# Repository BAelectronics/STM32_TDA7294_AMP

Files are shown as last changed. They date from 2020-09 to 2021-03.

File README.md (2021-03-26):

# Kapcsolódó videók / Related videos
[Part 1 (showing)](https://youtu.be/A-13wsFyjP8)
The language of the video is Hungarian, but English subtitles are available.

[Part 2 (HW & SW részletek)](https://youtu.be/WkM5X-X5rjU)

# STM32 vezérelt TDA7294 erősítő
A videóban bemutatott és a projekthez tartozó fájlok, rajzok, kódok stb.

A vezérlőpanel kapcsolása és nyákterve KiCad 5.1 programmal készült.
Az erősítőpanel és a táppanel Sprint Layout 5.0 programmal készült.
Az erősítőpanel kapcsolási rajza nem saját tervezés, ez képként megtalálható.

# STM32 Controlled TDA7294 Amplifier
Files, schematics, codes, etc. Everything what presented in the video and associated with the project.

The control board schematic and PCB designed with KiCad 5.1.
The amplifier board and power supply board designed with Sprint Layout 5.0.
The schematic of the amplifier board is not my own design, it can be found as picture.

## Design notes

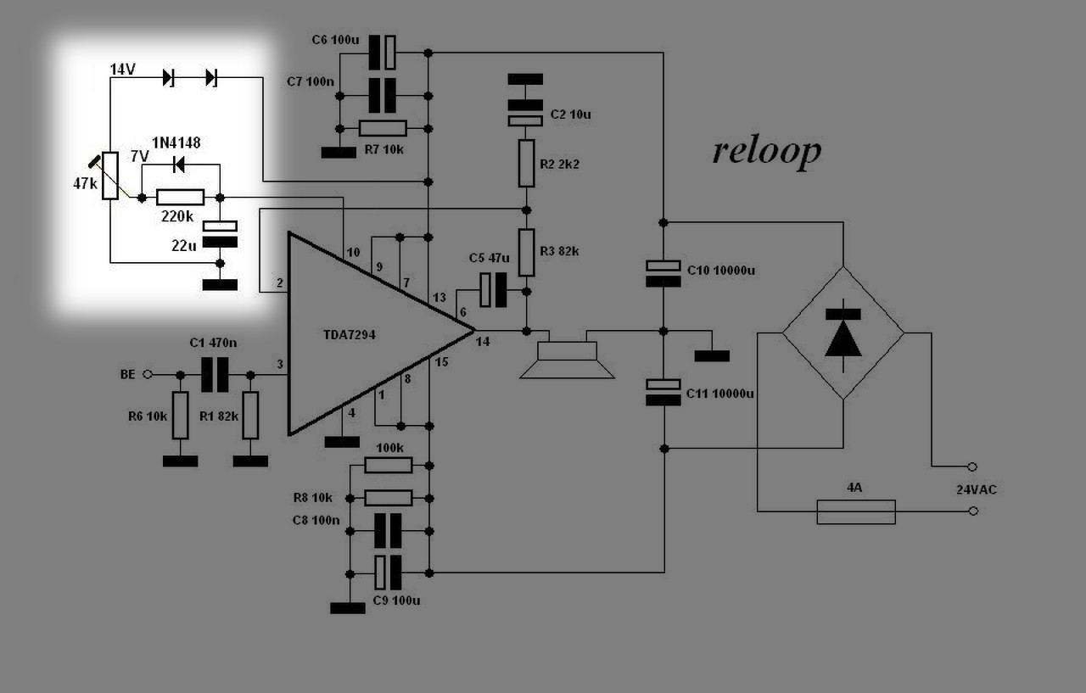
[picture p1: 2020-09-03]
1.4 ENG/Amplifier + power supply/Amplifier additional schematic.JPG

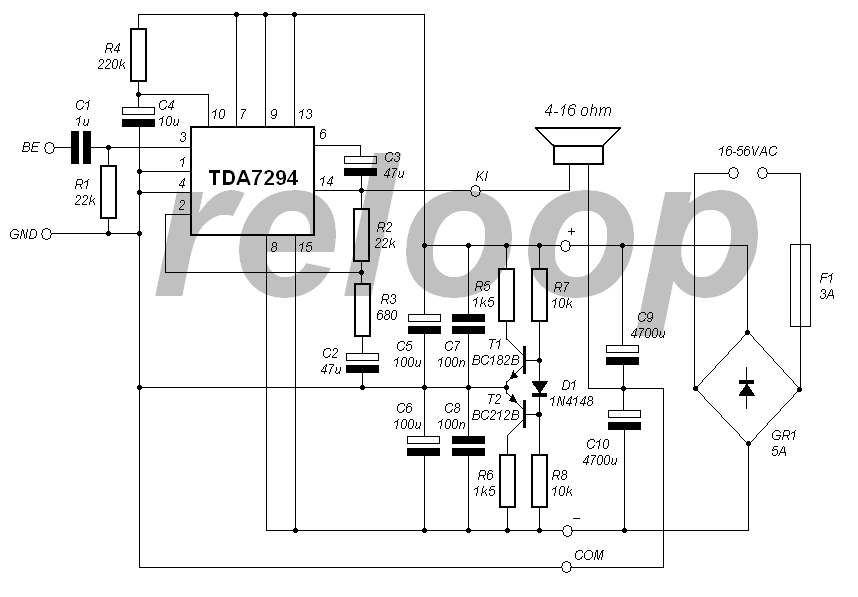
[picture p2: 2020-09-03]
1.4 ENG/Amplifier + power supply/Amplifier base schematic.PNG

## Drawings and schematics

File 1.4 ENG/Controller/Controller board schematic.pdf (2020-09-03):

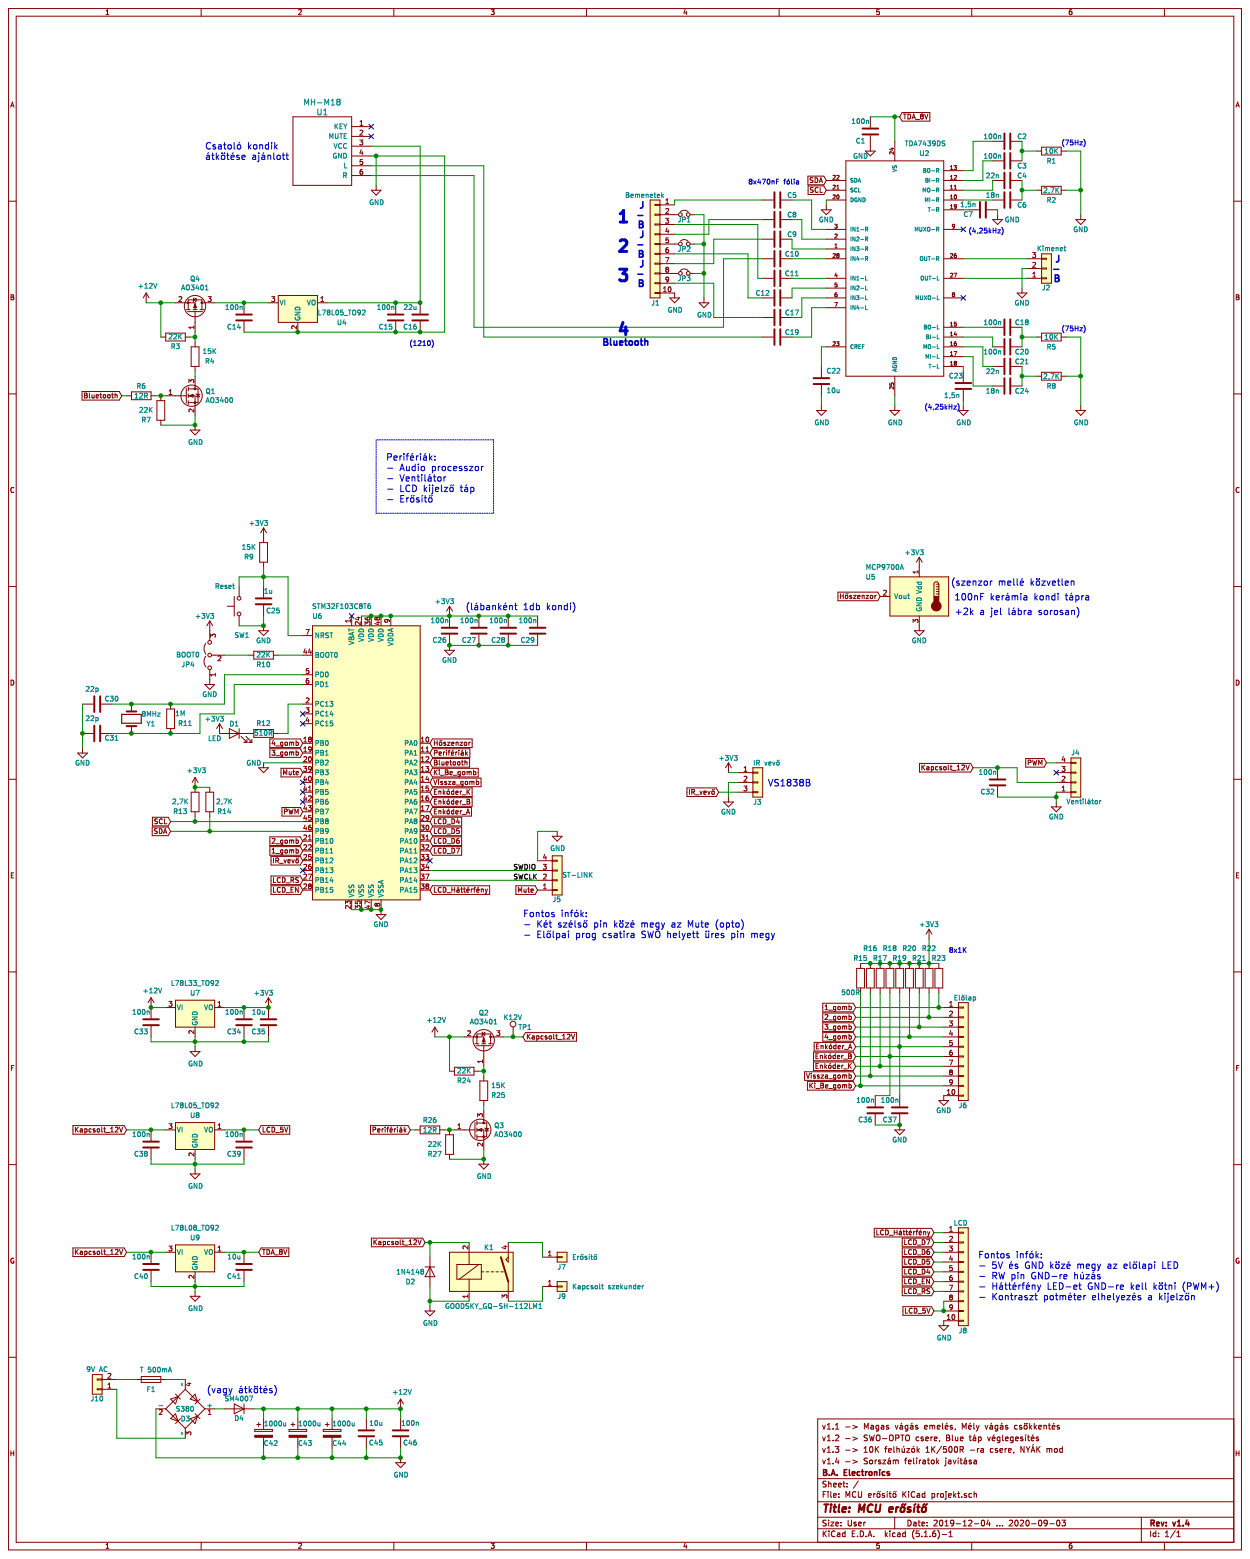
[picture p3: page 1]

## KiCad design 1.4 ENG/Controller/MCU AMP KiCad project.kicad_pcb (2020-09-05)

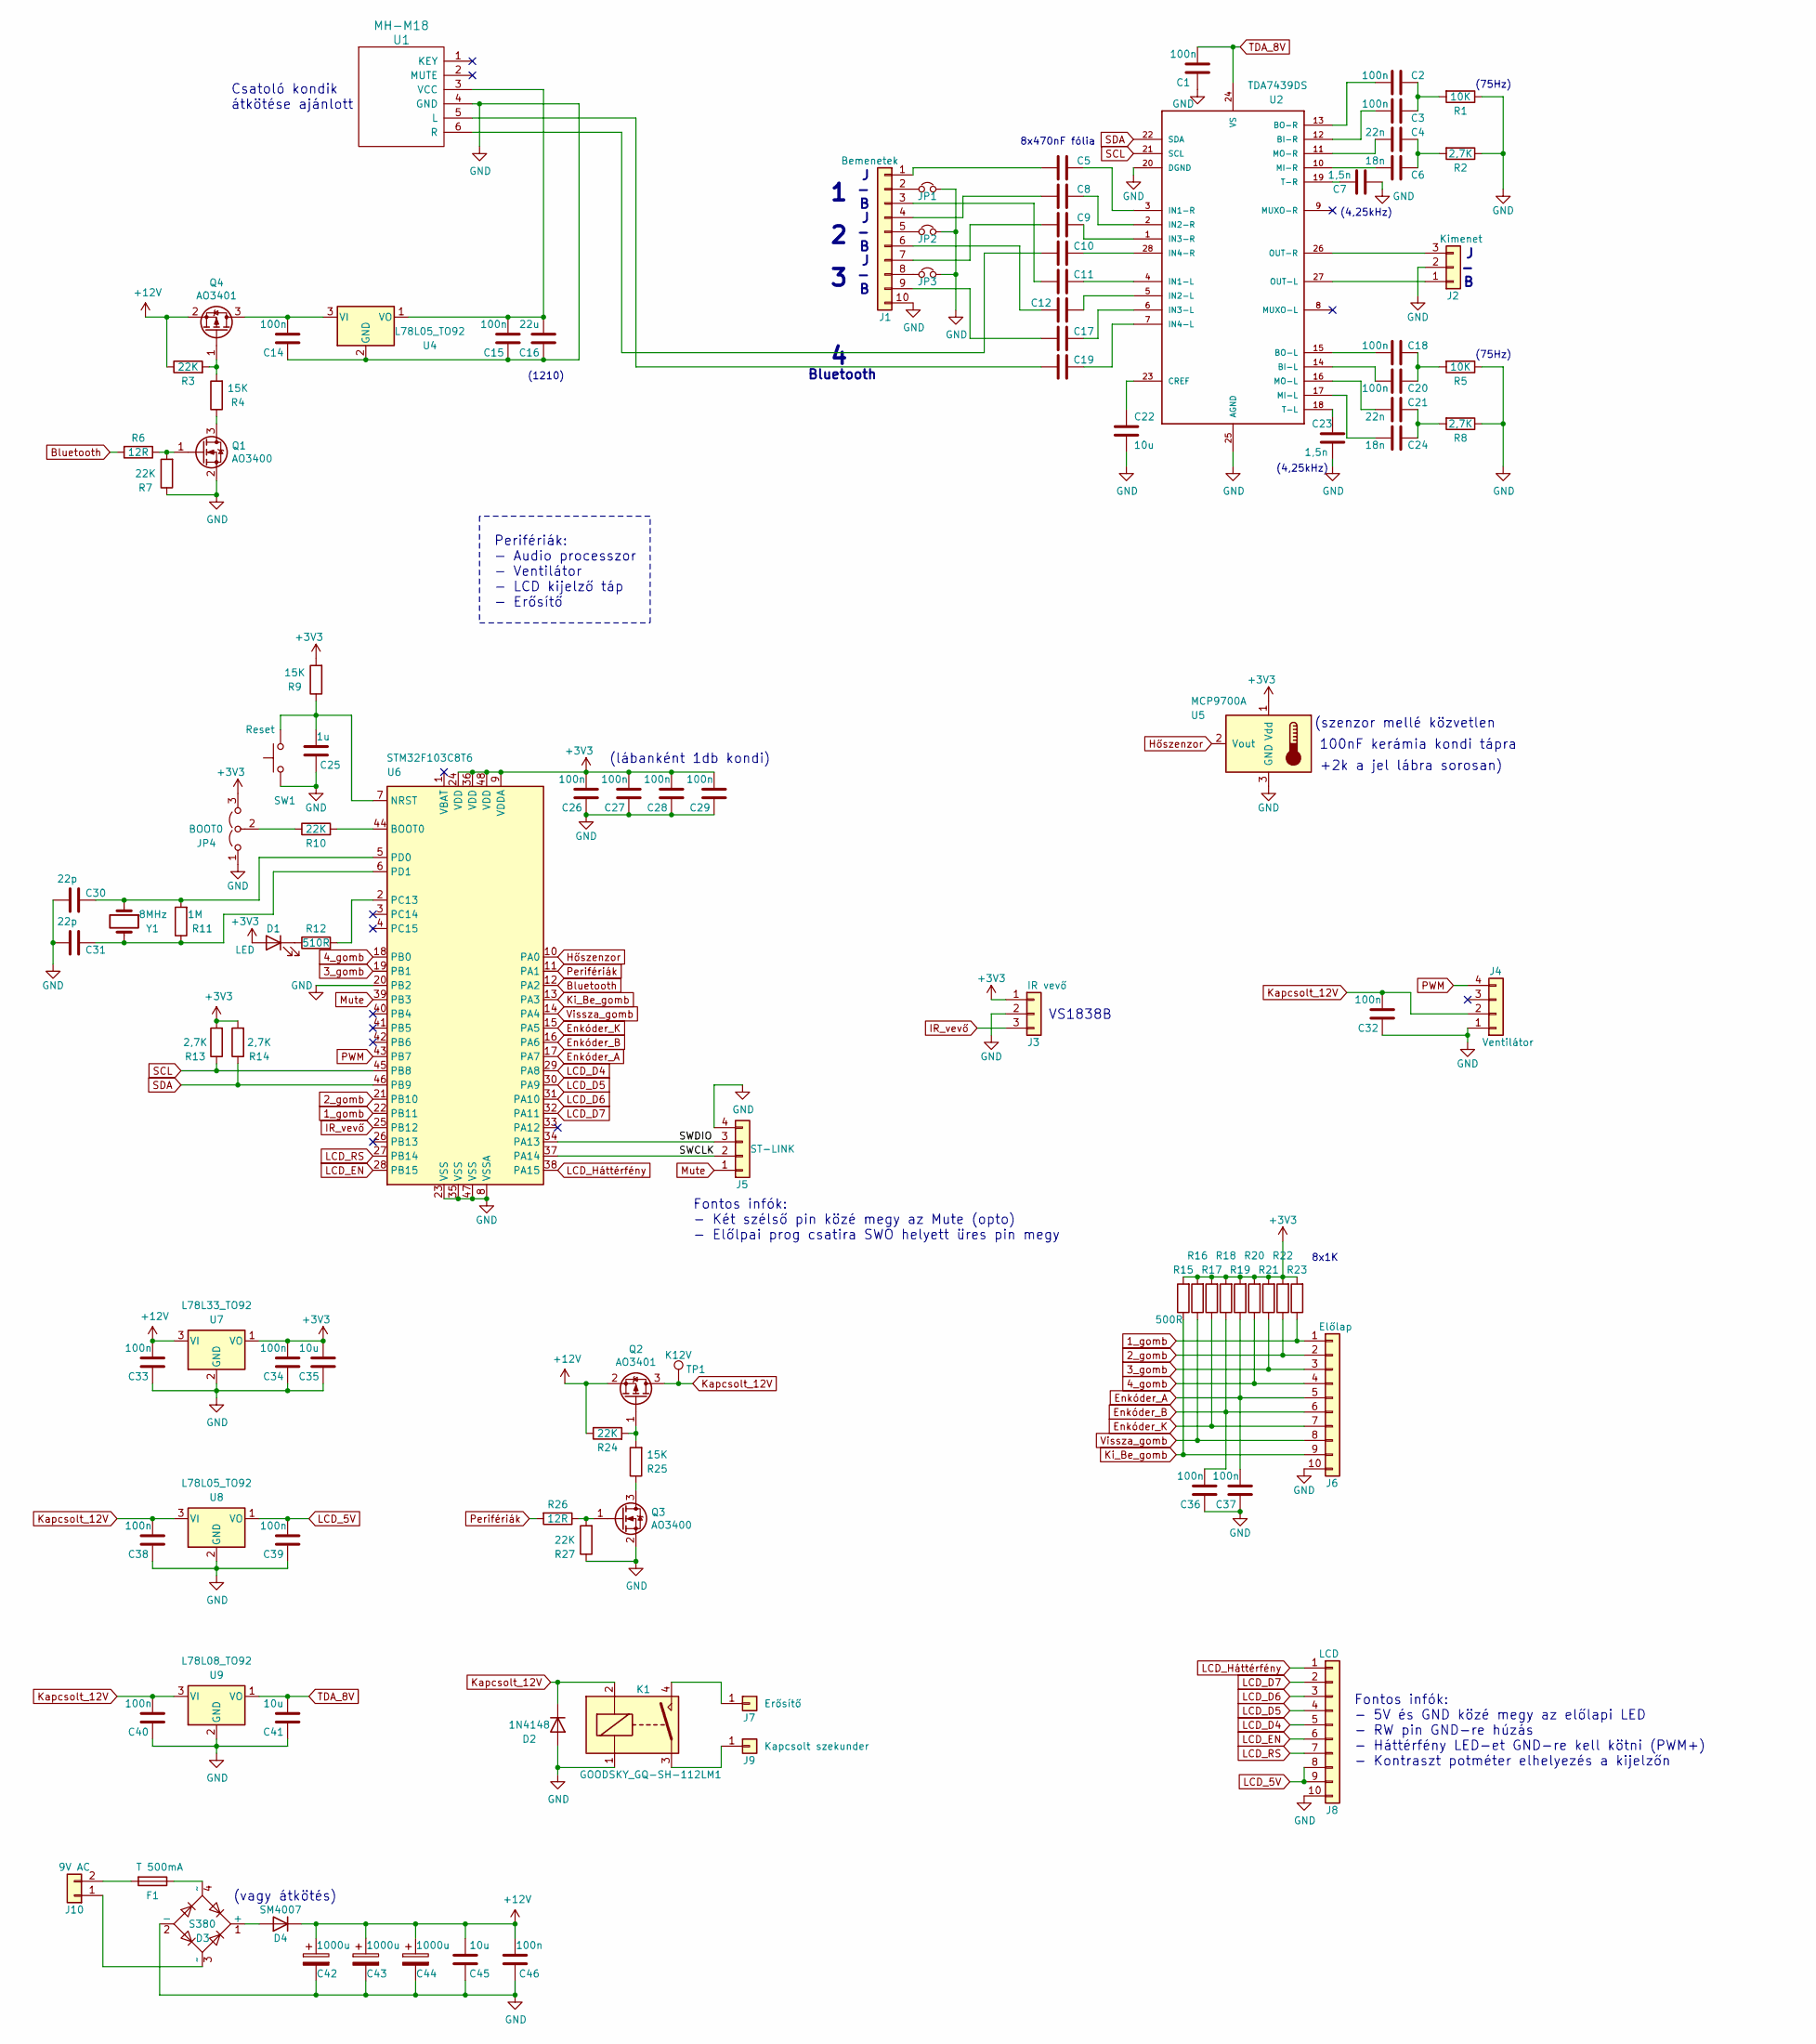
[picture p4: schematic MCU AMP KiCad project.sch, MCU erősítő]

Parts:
C1, C14, C15, C26, C27, C28, C29, C32, C33, C34, C36, C37, C38, C39, C40, C46: 100n; C_0805_2012Metric
C2, C3, C18, C20: 100n; C_Rect_L7.0mm_W2.5mm_P5.00mm
C4, C21: 22n; C_Rect_L7.0mm_W2.5mm_P5.00mm
C5, C8, C9, C10, C11, C12, C17, C19: 470n; C_Rect_L7.2mm_W3.5mm_P5.00mm_FKS2_FKP2_MKS2_MKP2
C6, C24: 18n; C_Rect_L7.0mm_W2.5mm_P5.00mm
C7, C23: 1,5n; C_Rect_L7.0mm_W2.5mm_P5.00mm
C16: 22u; C_1210_3225Metric
C22, C35, C41, C45: 10u; C_1206_3216Metric
C25: 1u; C_0805_2012Metric
C30, C31: 22p; C_0805_2012Metric
C42, C43, C44: 1000u; CP_Radial_D8.0mm_P3.50mm
D1: LED; LED_0805_2012Metric
D2: 1N4148; D_DO-35_SOD27_P7.62mm_Horizontal
D3: S380; Diode_Bridge_TO-269AA
D4: SM4007; D_MELF
F1: T 500mA; Fuse_Littelfuse_372_D8.50mm
J1: Bemenetek; JST_PH_B10B-PH-K_1x10_P2.00mm_Vertical
J2: Kimenet; JST_PH_B3B-PH-K_1x03_P2.00mm_Vertical
J3: IR vevő; JST_PH_B3B-PH-K_1x03_P2.00mm_Vertical
J4: Ventilátor; Molex_KK-254_AE-6410-04A_1x04_P2.54mm_Vertical
J5: ST-LINK; JST_PH_B4B-PH-K_1x04_P2.00mm_Vertical
J6: Előlap; JST_PH_B10B-PH-K_1x10_P2.00mm_Vertical
J7: Erősítő; SolderWirePad_1x02_P5.08mm_Drill1.5mm_saru
J8: LCD; JST_PH_B10B-PH-K_1x10_P2.00mm_Vertical
J9: Kapcsolt szekunder; SolderWirePad_1x02_P5.08mm_Drill1.5mm_saru
J10: 9V AC; TerminalBlock_RND_205-00012_1x02_P5.00mm_Horizontal
JP1: Jumper_1_GND; SolderJumper-2_P1.3mm_Open_Pad1.0x1.5mm
JP2: Jumper_2_GND; SolderJumper-2_P1.3mm_Open_Pad1.0x1.5mm
JP3: Jumper_3_GND; SolderJumper-2_P1.3mm_Open_Pad1.0x1.5mm
JP4: BOOT0; PinHeader_1x03_P2.54mm_Vertical
K1: GOODSKY_GQ-SH-112LM1
Q1, Q3: AO3400; SOT-23
Q2, Q4: AO3401; SOT-23
R1, R5: 10K; R_0805_2012Metric
R2, R8, R13, R14: 2,7K; R_0805_2012Metric
R3, R7, R10, R24, R27: 22K; R_0805_2012Metric
R4, R9: 15K; R_0805_2012Metric
R6, R26: 12R; R_0805_2012Metric
R11: 1M; R_0805_2012Metric
R12: 510R; R_0805_2012Metric
R15: 500R; R_0805_2012Metric
R16, R17, R18, R19, R20, R21, R22, R23: 1K; R_0805_2012Metric
R25: 15K; R_1206_3216Metric
SW1: Reset; SW_SPST_FSMSM
TP1: K12V; TestPoint_Pad_D1.0mm
U1: MH-M18; MH-M18_Bluetooth_Audio
U2: TDA7439DS; SOIC-28W_7.5x17.9mm_P1.27mm
U4, U8: L78L05_TO92; TO-92_Inline_mod
U5: MCP9700A; JST_PH_B3B-PH-K_1x03_P2.00mm_Vertical
U6: STM32F103C8T6; LQFP-48_7x7mm_P0.5mm
U7: L78L33_TO92; TO-92_Inline_mod
U9: L78L08_TO92; TO-92_Inline_mod
Y1: 8MHz; Crystal_HC49-U_Vertical

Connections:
1_gomb: J6.1, R23.1, U6.22 (PB11)
2_gomb: J6.2, R22.1, U6.21 (PB10)
3_gomb: J6.3, R21.1, U6.19 (PB1)
4_gomb: J6.4, R20.1, U6.18 (PB0)
+3V3: C26.2, C27.2, C28.2, C29.2, C34.2, C35.2, D1.2 (A), J3.1, JP4.3 (B), R9.2, R13.2, R14.2, R15.2, R16.2, R17.2, R18.2, R19.2, R20.2, R21.2, R22.2, R23.2, U5.1 (Vdd), U6.9 (VDDA), U6.24 (VDD), U6.36 (VDD), U6.48 (VDD), U7.1 (VO)
+12V: C33.2, C42.1, C43.1, C44.1, C45.2, C46.2, D4.1 (K), Q2.2 (S), Q4.2 (S), R3.1, R24.1, U7.3 (VI)
/SWCLK: J5.2, U6.37 (PA14)
/SWDIO: J5.3, U6.34 (PA13)
Bluetooth: R6.2, U6.12 (PA2)
Enkóder_A: C37.2, J6.5, R19.1, U6.17 (PA7)
Enkóder_B: C36.2, J6.6, R18.1, U6.16 (PA6)
Enkóder_K: J6.7, R17.1, U6.15 (PA5)
GND: C1.1, C7.2, C14.1, C15.1, C16.1, C22.1, C23.1, C25.1, C26.1, C27.1, C28.1, C29.1, C30.1, C31.1, C32.1, C33.1, C34.1, C35.1, C36.1, C37.1, C38.1, C39.1, C40.1, C41.1, C42.2, C43.2, C44.2, C45.1, C46.1, D2.2 (A), D3.2 (-), J1.10, J2.2, J3.2, J4.1, J5.4, J6.10, J8.10, JP1.2, JP2.2, JP3.2, JP4.1 (A), K1.1, Q1.2 (S), Q3.2 (S), R1.1, R2.1, R5.1, R7.1, R8.1, R27.1, SW1.1, U1.4 (GND), U2.20 (DGND), U2.25 (AGND), U4.2 (GND), U5.3 (GND), U6.8 (VSSA), U6.20 (PB2), U6.23 (VSS), U6.35 (VSS), U6.47 (VSS), U7.2 (GND), U8.2 (GND), U9.2 (GND)
Hőszenzor: U5.2 (Vout), U6.10 (PA0)
IR_vevő: J3.3, U6.25 (PB12)
Kapcsolt_12V: C32.2, C38.2, C40.2, D2.1 (K), J4.2, K1.2, Q2.3 (D), TP1.1, U8.3 (VI), U9.3 (VI)
Ki_Be_gomb: J6.9, R15.1, U6.13 (PA3)
LCD_5V: C39.2, J8.8, J8.9, U8.1 (VO)
LCD_D4: J8.5, U6.29 (PA8)
LCD_D5: J8.4, U6.30 (PA9)
LCD_D6: J8.3, U6.31 (PA10)
LCD_D7: J8.2, U6.32 (PA11)
LCD_EN: J8.6, U6.28 (PB15)
LCD_Háttérfény: J8.1, U6.38 (PA15)
LCD_RS: J8.7, U6.27 (PB14)
Mute: J5.1, U6.39 (PB3)
unnamed: C2.1, C3.1, R1.2
unnamed: C2.2, U2.13 (BO-R)
unnamed: C3.2, U2.12 (BI-R)
unnamed: C4.1, C6.1, R2.2
unnamed: C4.2, U2.11 (MO-R)
unnamed: C5.1, U2.3 (IN1-R)
unnamed: C5.2, J1.1
unnamed: C6.2, U2.10 (MI-R)
unnamed: C7.1, U2.19 (T-R)
unnamed: C8.1, U2.2 (IN2-R)
unnamed: C8.2, J1.4
unnamed: C9.1, U2.1 (IN3-R)
unnamed: C9.2, J1.7
unnamed: C10.1, U2.28 (IN4-R)
unnamed: C10.2, U1.6 (R)
unnamed: C11.1, U2.4 (IN1-L)
unnamed: C11.2, J1.3
unnamed: C12.1, U2.5 (IN2-L)
unnamed: C12.2, J1.6
unnamed: C14.2, Q4.3 (D), U4.3 (VI)
unnamed: C15.2, C16.2, U1.3 (VCC), U4.1 (VO)
unnamed: C17.1, U2.6 (IN3-L)
unnamed: C17.2, J1.9
unnamed: C18.1, C20.1, R5.2
unnamed: C18.2, U2.15 (BO-L)
unnamed: C19.1, U2.7 (IN4-L)
unnamed: C19.2, U1.5 (L)
unnamed: C20.2, U2.14 (BI-L)
unnamed: C21.1, C24.1, R8.2
unnamed: C21.2, U2.16 (MO-L)
unnamed: C22.2, U2.23 (CREF)
unnamed: C23.2, U2.18 (T-L)
unnamed: C24.2, U2.17 (MI-L)
unnamed: C25.2, R9.1, SW1.2, U6.7 (NRST)
unnamed: C30.2, R11.2, U6.5 (PD0), Y1.1
unnamed: C31.2, R11.1, U6.6 (PD1), Y1.2
unnamed: D1.1 (K), R12.1
unnamed: D3.1 (+), D4.2 (A)
unnamed: D3.3 (~~), J10.1
unnamed: D3.4 (~~), F1.1
unnamed: F1.2, J10.2
unnamed: J1.2, JP1.1
unnamed: J1.5, JP2.1
unnamed: J1.8, JP3.1
unnamed: J2.1, U2.27 (OUT-L)
unnamed: J2.3, U2.26 (OUT-R)
unnamed: J7.1, K1.4
unnamed: J9.1, K1.3
unnamed: JP4.2 (C), R10.1
unnamed: Q1.1 (G), R6.1, R7.2
unnamed: Q1.3 (D), R4.1
unnamed: Q2.1 (G), R24.2, R25.2
unnamed: Q3.1 (G), R26.1, R27.2
unnamed: Q3.3 (D), R25.1
unnamed: Q4.1 (G), R3.2, R4.2
unnamed: R10.2, U6.44 (BOOT0)
unnamed: R12.2, U6.2 (PC13)
PWM: J4.4, U6.43 (PB7)
Perifériák: R26.2, U6.11 (PA1)
SCL: R13.1, U2.21 (SCL), U6.45 (PB8)
SDA: R14.1, U2.22 (SDA), U6.46 (PB9)
TDA_8V: C1.2, C41.2, U2.24 (VS), U9.1 (VO)
Vissza_gomb: J6.8, R16.1, U6.14 (PA4)

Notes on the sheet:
8x470nF fólia
(vagy átkötés)
(lábanként 1db kondi)
(szenzor mellé közvetlen
100nF kerámia kondi tápra
8x1K
Perifériák: - Audio processzor - Ventilátor - LCD kijelző táp - Erősítő
+2k a jel lábra sorosan)
(1210)
Fontos infók: - 5V és GND közé megy az előlapi LED - RW pin GND-re húzás - Háttérfény LED-et GND-re kell kötni (PWM+) - Kontraszt potméter elhelyezés a kijelzőn
Bluetooth
Csatoló kondik átkötése ajánlott
(75Hz)
(4,25kHz)
Fontos infók: - Két szélső pin közé megy az Mute (opto) - Előlpai prog csatira SWO helyett üres pin megy
VS1838B

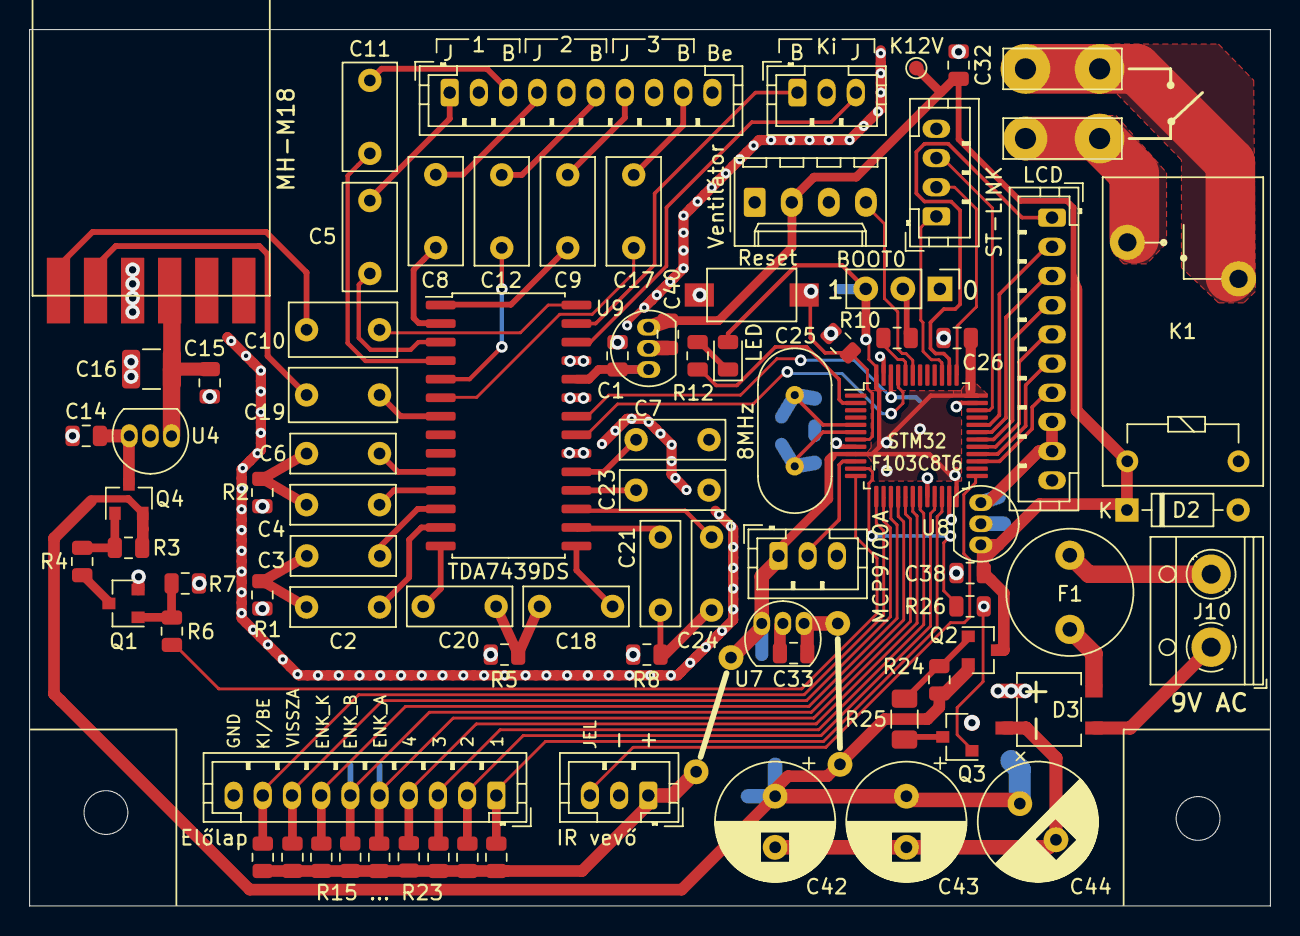
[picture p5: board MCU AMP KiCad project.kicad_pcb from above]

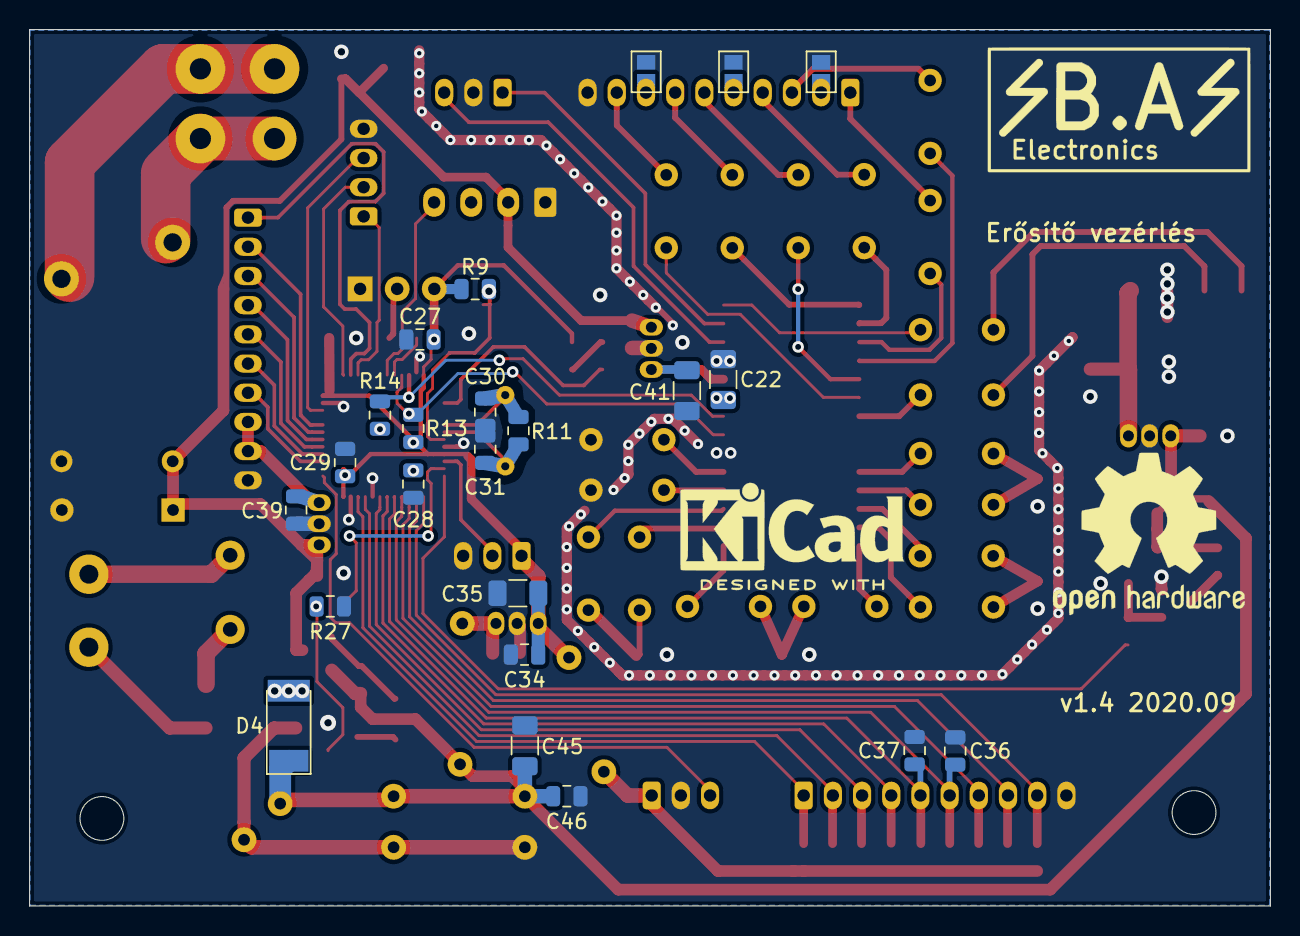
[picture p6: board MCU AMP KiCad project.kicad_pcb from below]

Board: 2 copper layers, 85.0 x 60.0 mm, 107 parts (23 on the bottom side), 89 nets.
